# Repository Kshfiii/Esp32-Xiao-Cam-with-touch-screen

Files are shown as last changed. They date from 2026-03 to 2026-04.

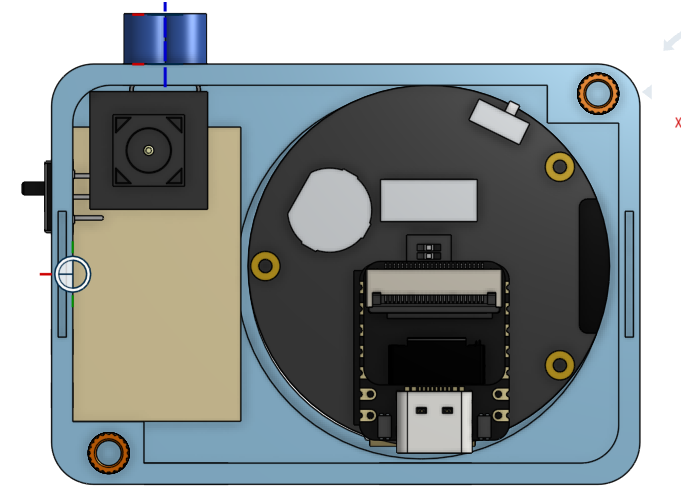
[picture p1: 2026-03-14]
Assembly/Assembly_open.PNG

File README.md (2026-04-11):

# Xiao esp32-s3 sense based Camera with touch screen

XIAO Cam is a small camera built around the Seeed Studio XIAO ESP32-S3 Sense microcontroller. It displays a live camera feed on a 1.28" round touchscreen, captures photos to a microSD card with a  button press, and lets you browse your shots through a swipe-based gallery; housed inside a custom 3D printed case.
It's for people who are interested in a simple hardware build that actually serves a function. 

## About

XIAO Cam is a custom point-and-shoot camera built from scratch. I did everything myself, from the 3d printed case to the firmware and component selection.

I made this because I wanted to sharpen my CAD skills. I challenged myself to build something that actually works as a real device, and looks professional. Plus I've wanted to buy a digi cam for a while and i thought why not make it myself.
## Usage & Features

1. Power on using the slide switch on the side camera
2. The round screen shows a live camera feed automatically on boot
3. Press the shutter button on the right side of the case to take a photo — it saves instantly to the SD card
4. Swipe up on the touchscreen to open the photo gallery
Swipe left or right to browse your saved photos
5. Swipe down to return to the live viewfinder
6. Charge via the USB-C port on the XIAO esp32 s3 sense

#
P.s. There is a placeholder to attach a lanyard to the camera for practicality.

## Project Images
Assembly_front
case
cad

📎 OnShape CAD model (public link): [https://cad.onshape.com/documents/d0d02c920c1d3887f88da338/w/cd12746e145d8d660cbdb08a/e/dfaf3792be18770a6bf41023]

## Firmware setup

Required Libraries:

TFT_eSPI by Bodmer
TJpg_Decoder by Bodmer
Seeed_Arduino_RoundDisplay by Seeed Studio
ESP32 board package by Espressif (via Board Manager)

#Steps before flashing:

1. Cut J3 on the Sense expansion board — see Hardware Note below
2. In TFT_eSPI/User_Setup_Select.h, uncomment:

cpp   #include <User_Setups/Setup202_Seeed_XIAO_Round_Display.h>

3. In Arduino IDE: Tools → Board → XIAO_ESP32S3
4. Tools → PSRAM → OPI PSRAM ← do not skip this, camera will not work without it
5. Upload firmware/xiao_cam/xiao_cam.ino

## Firmware files:

_Files and their functions:_

1. xiao_cam.inoMain : loop and state machine
2. config.hAll : pin definitions and settings
3. camera.h : Camera init and frame 
4. capturesd_card.hSD card init, save photos, list files
5. gallery.hSwipe-based photo gallery

## Hardware Note — J3 Solder Jumper

The XIAO ESP32-S3 Sense and the Round Display both have SD card pull-up resistors on the same SPI lines. This causes a conflict and neither SD slot will work unless you fix it.

_Steps to Fix:_

1. Remove the camera ribbon cable from the Sense board
Flip the Sense expansion board over and find the J3 solder jumper
2. Slice through the solder bridge with a hobby knife
3. Verify with a multimeter that there is no continuity across J3.

This disables the sd card slot of the esp32-sense 
 (don't worry, it's reversible. Just solder J3 back)

## Component List

1. Seeed studio Xiao Esp32-s3 sense
2. 3.7v 400mah rechargeable Lipo Battery 
3. Xiao Esp32 S3 1.28" round touch screen Display
4. Seeed studio OV5640 Camera
5. Tactile switch 
6. Slide switch

## Bill of Materials
| Component | Quantity | Est. Cost (USD) | Purchase Links | 
| :--- | :---: | :--- | :--- |
| **Seeed studio Xiao Esp32-s3 sense**| 1 | $16.50 | https://www.aliexpress.com/item/1005006988111963.html | 
| **Xiao Esp32 S3 1.28in round touch screen**| 1 | $21.00 | https://www.aliexpress.com/item/1005006989795918.html | 
| ** Tactile Switch Set (20pcs)** | 1 | $1.20 |https://www.aliexpress.com/item/1005005845072975.html | 
| ** Brass Inserts** | 1 | $2.50 | https://www.aliexpress.com/item/1005008684741327.html | 
| ** 3.7V 400mAh LiPo Battery** | 1 | $0.50 | https://digilog.pk/products/3-7v-300mah-602030-rechargeable-lithium-polymer-battery-lipo-cells | 
| **Total Build Cost:** |  | **~$43.00** |

#
Happy Building :)

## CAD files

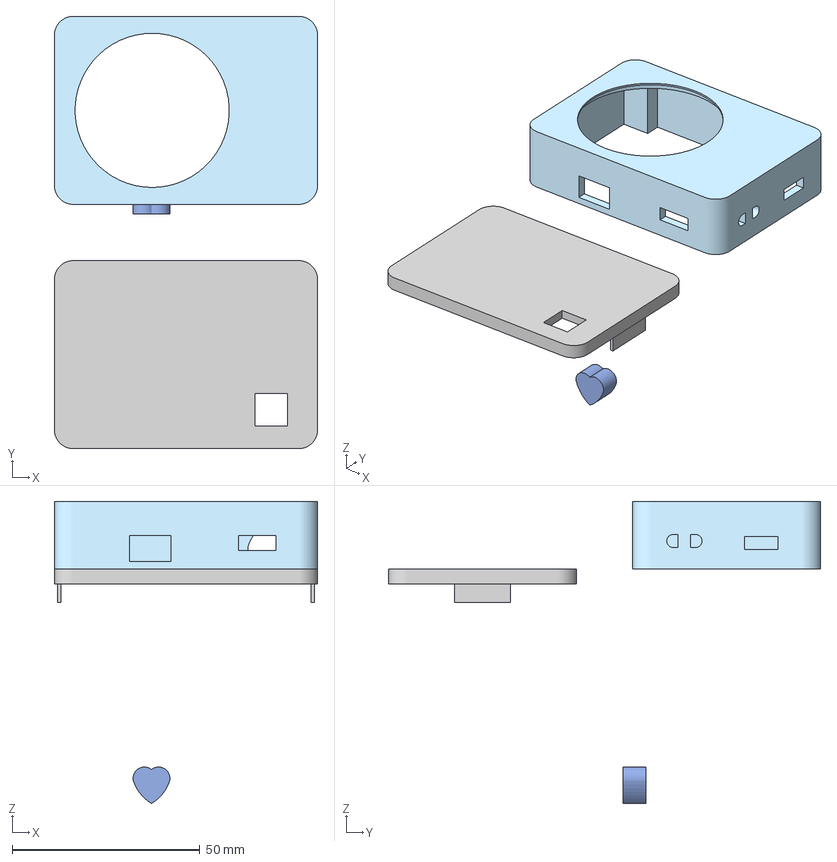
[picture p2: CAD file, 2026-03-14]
Assembly/Cam_body.3mf
70.0 x 115.0 x 80.3 mm

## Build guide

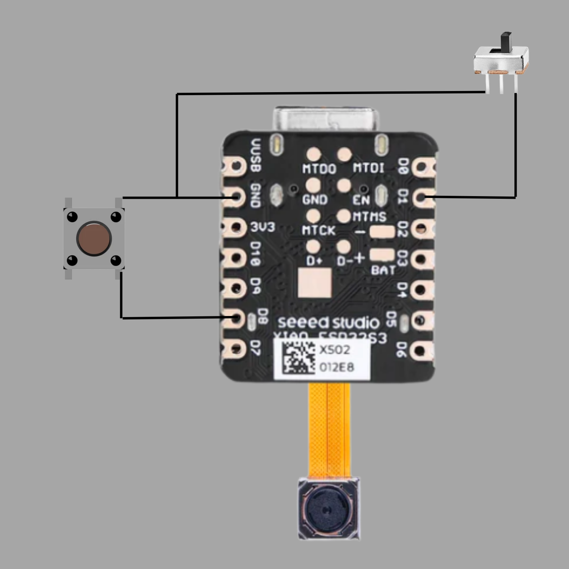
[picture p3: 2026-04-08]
Wiring Diagram.png

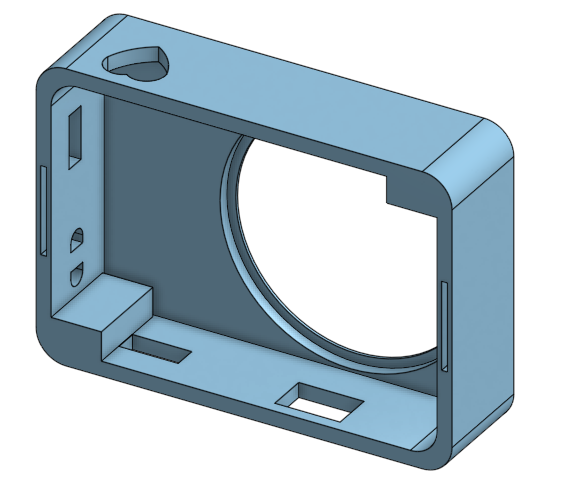
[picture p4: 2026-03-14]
Assembly/Body_Part1_back.PNG

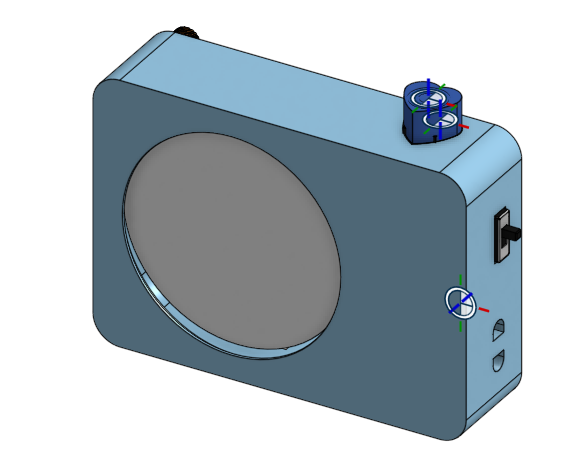
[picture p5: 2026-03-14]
Assembly/Assembly_front.PNG

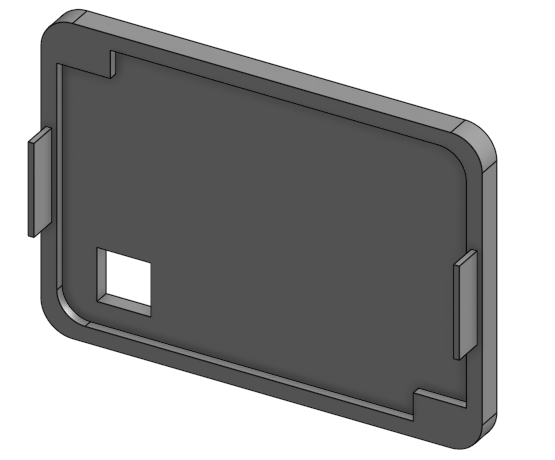
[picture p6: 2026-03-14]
Assembly/Body_Part2_Back.PNG

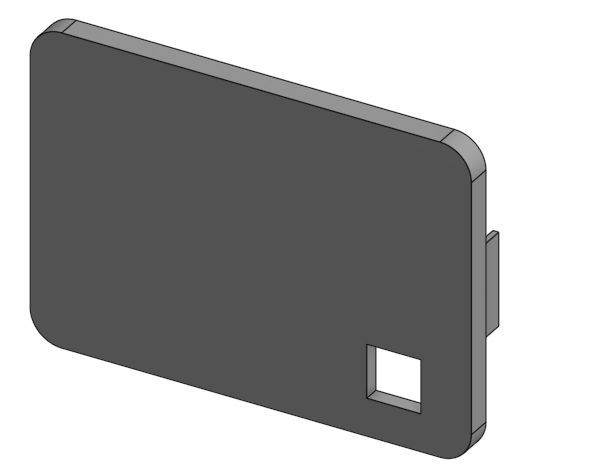
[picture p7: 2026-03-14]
Assembly/Body_Part2_front.PNG

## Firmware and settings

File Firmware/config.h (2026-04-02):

#pragma once

#define PIN_SHUTTER        D0
#define SD_CS_PIN          D2
#define SCREEN_W           240
#define SCREEN_H           240
#define CAM_PIN_PWDN       -1
#define CAM_PIN_RESET      -1
#define CAM_PIN_XCLK       10
#define CAM_PIN_SIOD       40
#define CAM_PIN_SIOC       39
#define CAM_PIN_Y9         48
#define CAM_PIN_Y8         11
#define CAM_PIN_Y7         12
#define CAM_PIN_Y6         14
#define CAM_PIN_Y5         16
#define CAM_PIN_Y4         18
#define CAM_PIN_Y3         17
#define CAM_PIN_Y2         15
#define CAM_PIN_VSYNC      38
#define CAM_PIN_HREF       47
#define CAM_PIN_PCLK       13
#define PHOTO_QUALITY      10
#define SWIPE_THRESHOLD    40

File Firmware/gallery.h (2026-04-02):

#pragma once
#include <TFT_eSPI.h>
#include <TJpg_Decoder.h>
#include <SD.h>
#include "sd_card.h"
#include "config.h"


extern TFT_eSPI tft;

static std::vector<String> _photos;
static int _current = 0;

void gallery_load() {
  _photos = sd_list_photos();
  _current = _photos.empty() ? 0 : (int)_photos.size() - 1;
}

void gallery_draw() {
  tft.fillScreen(TFT_BLACK);

  if (_photos.empty()) {
    tft.setTextColor(TFT_DARKGREY, TFT_BLACK);
    tft.setTextSize(1);
    tft.setCursor(70, 108);
    tft.print("No photos yet.");
    tft.setCursor(62, 124);
    tft.print("Press shutter!");
    return;
  }


  File f = SD.open(_photos[_current]);
  if (f) {
    size_t sz = f.size();
    uint8_t *buf = (uint8_t*)ps_malloc(sz);
    if (buf) {
      f.read(buf, sz);
      f.close();
      TJpgDec.drawJpg(0, 0, buf, sz);
      free(buf);
    } else {
      f.close();
    }
  }


  String counter = String(_current + 1) + " / " + String(_photos.size());
  tft.setTextColor(TFT_WHITE, TFT_BLACK);
  tft.setTextSize(1);
  int16_t tw = tft.textWidth(counter);
  tft.fillRect((SCREEN_W - tw) / 2 - 4, 220, tw + 8, 14, TFT_BLACK);
  tft.setCursor((SCREEN_W - tw) / 2, 222);
  tft.print(counter);

 
  tft.setTextColor(TFT_DARKGREY, TFT_BLACK);
  tft.setCursor(52, 8);
  tft.print("swipe down: back");
}

void gallery_go_next() {
  if (_photos.empty()) return;
  _current = (_current + 1) % _photos.size();
  gallery_draw();
}

void gallery_go_prev() {
  if (_photos.empty()) return;
  _current = (_current - 1 + _photos.size()) % _photos.size();
  gallery_draw();
}

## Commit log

2026-03-14 Revise README to emphasize Xiao camera features
    Removed introductory section about 'Cute-Camera' to focus on 'Xiao esp32-s3 sense based Camera'.
2026-03-14 Fix typo in README about camera project
2026-03-14 Update README with hardware note and component list
    Added hardware note about J3 solder jumper and provided steps to fix SD card conflict.
2026-03-14 Add note about links in Bom.csv with prices
2026-03-14 Update Bill of Materials with component details
2026-03-14 Update and rename Bill of materials. csv to BOM.csv
    [BOM.csv]
2026-03-14 Update BOM.csv with new components and costs
    [BOM.csv]
2026-03-14 Revise purchase links in BOM.csv
    Updated purchase links for components in BOM.
    [BOM.csv]
2026-03-14 Remove 3D Printing costs from BOM.csv
    Removed 3D Printing costs entry from BOM.
    [BOM.csv]
2026-03-14 Revise BOM with updated components and costs
    Updated the BOM with new purchase links and adjusted total build cost.
    [BOM.csv]
2026-03-14 Fix typo in BOM for touch screen description
    [BOM.csv]
2026-04-11 Correct total build cost in BOM.csv
    Updated the total build cost in BOM.csv to reflect the new total.
    [BOM.csv]
